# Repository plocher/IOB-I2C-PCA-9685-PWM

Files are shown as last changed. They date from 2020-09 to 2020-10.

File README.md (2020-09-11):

# IOB-I2C-PCA-9685-PWM
## License: CERN Open Hardware Licence v1.2

IOB I2C PCA9685 PWN driver

### Specifications

 * The PCA9685 is an i2c-controlled PWM driver with a built in free running clock.
 * The board is 5V compliant, which means you can control it from a 3.3V microcontroller and still safely drive up to 6V outputs (for LEDS and Servos)
 * 6 address select pins support up to 62 of these on a single I2C bus
 * Adjustable frequency PWM up to about 1.6 KHz
 * 12-bit resolution for each output
 * Configurable push-pull or open-drain output
 * Output enable pin to quickly disable all the outputs

### Communication Protocol

```C++
Simple I2C 16-bit Reads and Writes:

void I2Cexpander::init9685(uint8_t i2caddr, uint16_t dir) {
    if (i2caddr < base9685) {
        _i2c_address = i2caddr + base9685;
    } else {
        _i2c_address = i2caddr;
    }
    Wire.beginTransmission(_i2c_address);
	Wire.write(PCA9685_MODE1);
	Wire.write(PCA9685_MODE1_SLEEP);
    Wire.endTransmission();  
    delay(1);
    // Set precaler: float prescaleval = ((_oscillator_freq / (freq * 4096.0)) + 0.5) - 1;
    // max 255, min 3
    // internal _oscillator_freq is 25MHz
    Wire.beginTransmission(_i2c_address);
	Wire.write(PCA9685_PRESCALE);
	Wire.write(6);	// a value of 6 is about a 1000 Hz refresh rate  Servos need 60Hz: 101
    Wire.endTransmission();  
    delay(1);
    Wire.beginTransmission(_i2c_address);
	Wire.write(PCA9685_MODE1);
	Wire.write(PCA9685_MODE1_RESTART | PCA9685_MODE1_AUTOINC | PCA9685_MODE1_ALLCALL);
    Wire.endTransmission();  
    delay(1);
    Wire.beginTransmission(_i2c_address);
	Wire.write(PCA9685_MODE2);
	Wire.write(PCA9685_MODE2_TOTEM | PCA9685_MODE2_OEOFF);
    Wire.endTransmission();  
    delay(1);
}

// read uses the config value to distinguish which LED to read/write

uint32_t I2Cexpander::read9685() {
    uint32_t data = 0;
    uint16_t startdata = 0;
    uint16_t stopdata = 0;
    Wire.beginTransmission(_i2c_address);
    Wire.write(PCA9685_BASE_LED0 + (_config * 4));
    int n = Wire.endTransmission(false);  
    if (! ((n == 0) || (n ==7)) ) {
		return (_last);
    }
    Wire.requestFrom(_i2c_address, (uint8_t)4, (uint8_t)1);
    startdata = Wire.read();
    startdata |= (Wire.read() << 8);  
    stopdata = Wire.read();
    stopdata |= (Wire.read() << 8);  
	if (stopdata == startdata)     data = 0;
	else if (stopdata < startdata) data = startdata + stopdata & 0x0FFF;
	else                           data = stopdata - startdata;
    return data;
}

void I2Cexpander::write9685(uint32_t data) {
    /*
     * The chip has a freerunning counter (0..4095, 0x0000 to 0x0FFF)
     * LED#_ON_H/L  bits 0..11 are start 'time' for turn on
     *    Bit 12 (0x1000) means CONSTANT ON, unless OFF bit is also set
     * LED#_OFF_H/L bits 0..11 are start 'time' for turn off
     *    Bit 12 (0x1000) means CONSTANT OFF, overrides any ON setting
     */
    data = data & 0x0FFF;

    //  Stagger starting phase to ensure each string is independent, to reduce power supply spiking
    int start = (_config * 0x0F); // use LED num as beginning count...

    unsigned int end = (data + start) % 0x0FFF;		// 12 bits = 4096
    int b1 = (start     ) & 0x00FF; // low byte ...
    int b2 = (start >> 8) & 0x000F; // ... and high nibble
    int e1 = (end       ) & 0x00FF; // low byte ...
    int e2 = (end   >> 8) & 0x000F; // ... and high nibble

    if (data == 0x0FFF) {		// FULL ON
        b2 |= 0x1000;
    } else if (data == 0x0000) {	// FULL OFF
        e2 |= 0x1000;
    }

    Wire.beginTransmission(_i2c_address);
    Wire.write(PCA9685_BASE_LED0 + (_config * 4));

    Wire.write(b1);  
    Wire.write(b2);  
    Wire.write(e1);  
    Wire.write(e2);  

    Wire.endTransmission();  
}

```

See [I2Cexpander-lib](/pages/I2Cexpander "wikilink") for a more complete interface
library.

### Addressing
The addres selection for the PCA9685 allows for 62 devices, addresses 0x40 to 0x7F.
The board has dip switches for A0 through A5, A6 is hardcoded to "1" in the chip.

**A6**|**A5**|**A4**|**A3**|**A2**|**A1**|**A0**|**ADDRESS (HEX)**
:-----:|:-----:|:-----:|:-----:|:-----:|:-----:|:-----:|:-----:
1|0|0| 0|0|0|0 | 0x40
1|0|0| 0|0|0|1 | 0x41
1|0|0| 0|0|1|0 | 0x42
1|0|0| 0|0|1|1 | 0x43
1|0|0| 0|1|0|0 | 0x44
1|0|0| 0|1|0|1 | 0x45
1|0|0| 0|1|1|0 | 0x46
1|0|0| 0|1|1|1 | 0x47
1|0|0| 1|0|0|0 | 0x48
1|0|0| 1|0|0|1 | 0x49
1|0|0| 1|0|1|0 | 0x4A
1|0|0| 1|0|1|1 | 0x4B
1|0|0| 1|1|0|0 | 0x4C
1|0|0| 1|1|0|1 | 0x4D
1|0|0| 1|1|1|0 | 0x4E
1|0|0| 1|1|1|1 | 0x4F
1|0|1| 0|0|0|0 | 0x50
1|0|1| 0|0|0|1 | 0x51
1|0|1| 0|0|1|0 | 0x52
1|0|1| 0|0|1|1 | 0x53
1|0|1| 0|1|0|0 | 0x54
1|0|1| 0|1|0|1 | 0x55
1|0|1| 0|1|1|0 | 0x56
1|0|1| 0|1|1|1 | 0x57
1|0|1| 1|0|0|0 | 0x58
1|0|1| 1|0|0|1 | 0x59
1|0|1| 1|0|1|0 | 0x5A
1|0|1| 1|0|1|1 | 0x5B
1|0|1| 1|1|0|0 | 0x5C
1|0|1| 1|1|0|1 | 0x5D
1|0|1| 1|1|1|0 | 0x5E
1|0|1| 1|1|1|1 | 0x5F
1|1|0| 0|0|0|0 | 0x60
1|1|0| 0|0|0|1 | 0x61
1|1|0| 0|0|1|0 | 0x62
1|1|0| 0|0|1|1 | 0x63
1|1|0| 0|1|0|0 | 0x64
1|1|0| 0|1|0|1 | 0x65
1|1|0| 0|1|1|0 | 0x66
1|1|0| 0|1|1|1 | 0x67
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

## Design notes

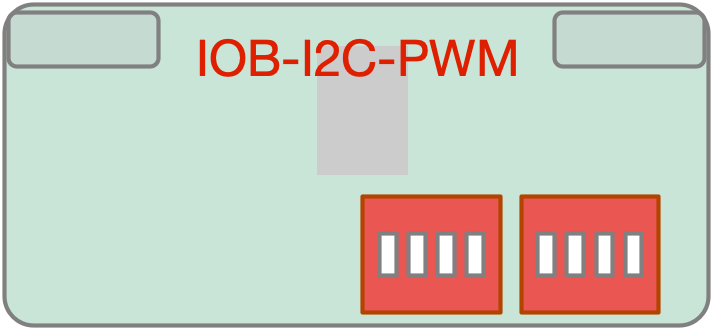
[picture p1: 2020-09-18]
IOB-I2C-PCA9685-PWM-Graphic.png

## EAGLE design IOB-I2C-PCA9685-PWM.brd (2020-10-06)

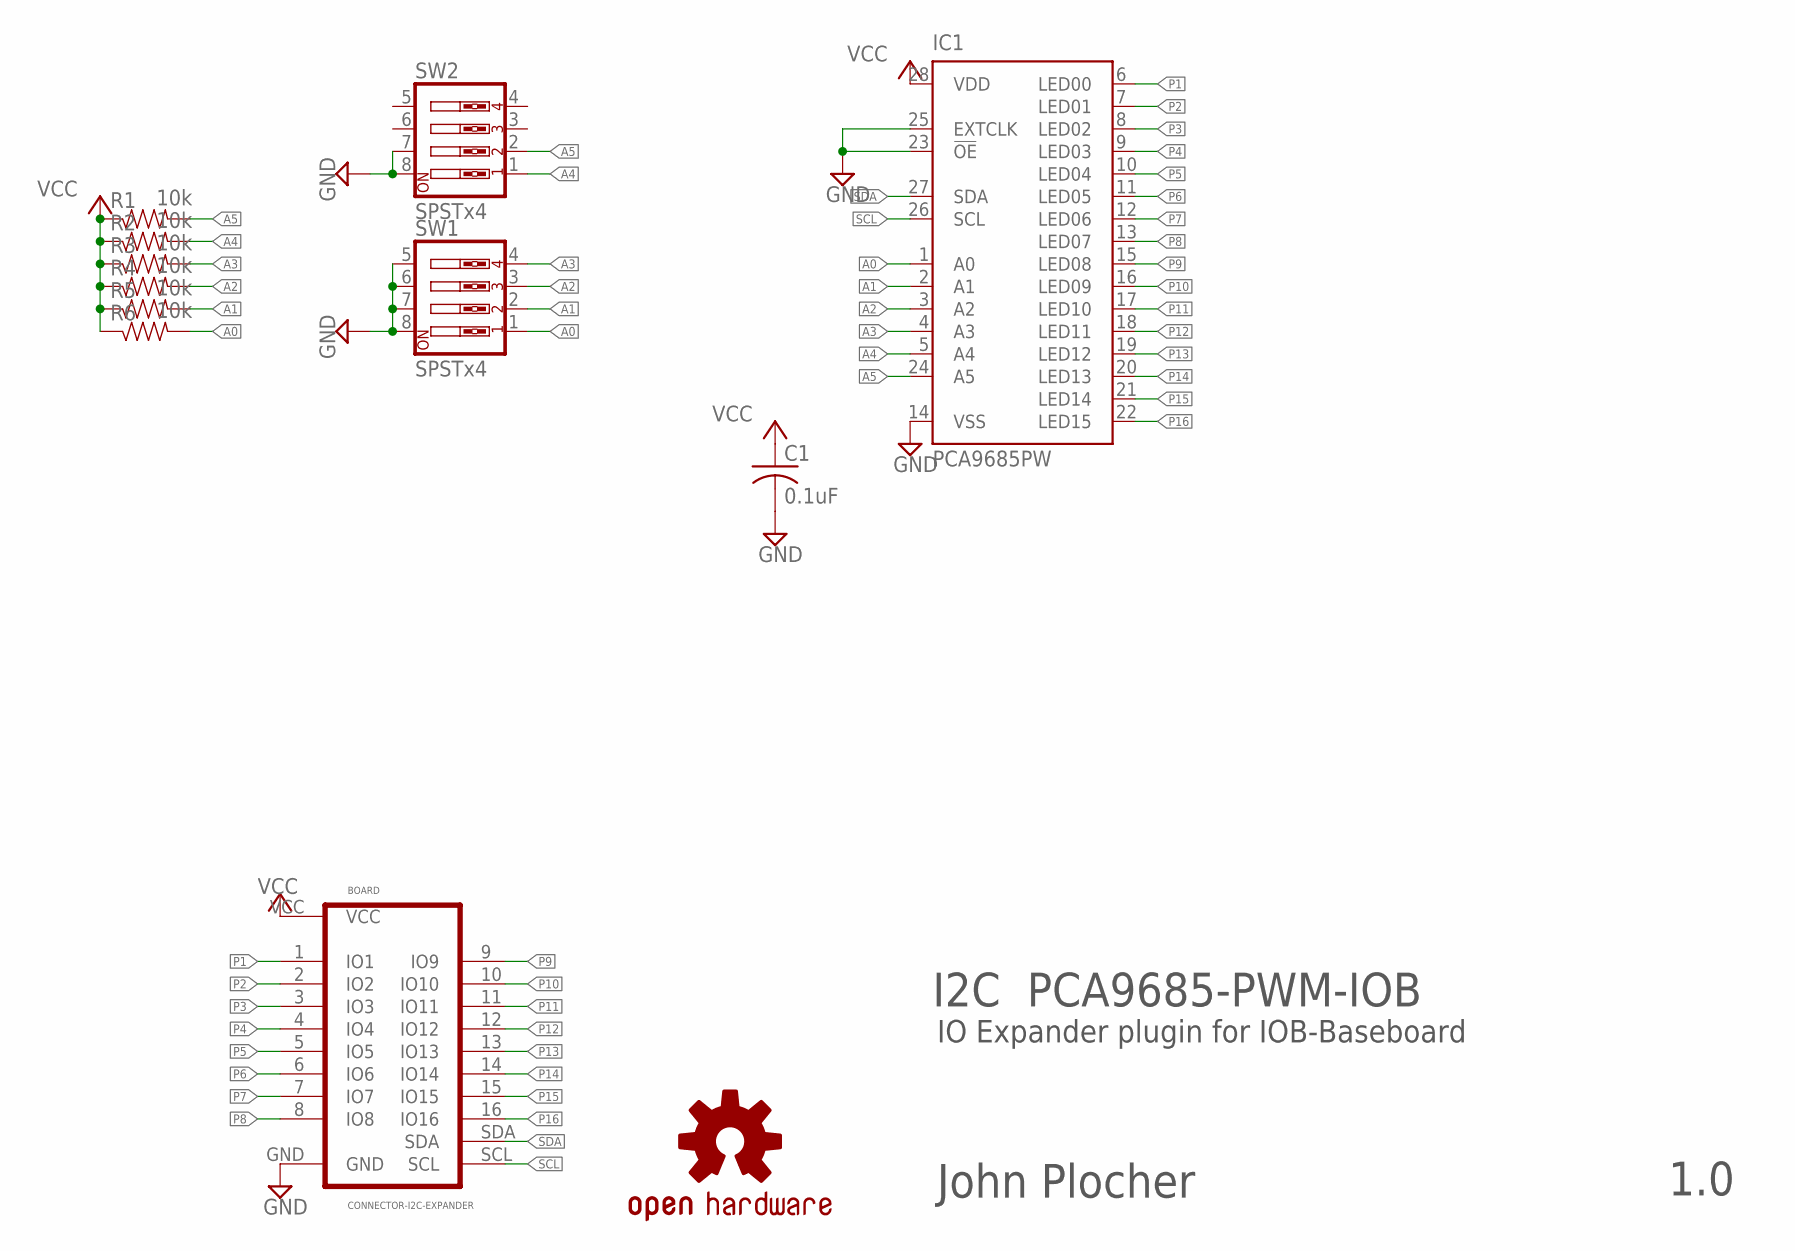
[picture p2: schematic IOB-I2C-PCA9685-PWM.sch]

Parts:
BOARD: CONNECTOR-I2C-EXPANDER; I2C-EXPANDER
C1: 0.1uF; 0603-CAP
IC1: PCA9685PW; TSSOP28
R1, R2, R3, R4, R5, R6: 10k; 0603-RES
SW1, SW2: SPSTx4; EDG-04
U$1: OSHW; OSHW-LOGO-L

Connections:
A0: IC1.1 (A0), R6.2, SW1.1
A1: IC1.2 (A1), R5.2, SW1.2
A2: IC1.3 (A2), R4.2, SW1.3
A3: IC1.4 (A3), R3.2, SW1.4
A4: IC1.5 (A4), R2.2, SW2.1
A5: IC1.24 (A5), R1.2, SW2.2
GND: BOARD.GND, C1.2, IC1.14 (VSS), IC1.23 (!OE), IC1.25 (EXTCLK), SW1.5, SW1.6, SW1.7, SW1.8, SW2.7, SW2.8
P1: BOARD.1 (IO1), IC1.6 (LED00)
P2: BOARD.2 (IO2), IC1.7 (LED01)
P3: BOARD.3 (IO3), IC1.8 (LED02)
P4: BOARD.4 (IO4), IC1.9 (LED03)
P5: BOARD.5 (IO5), IC1.10 (LED04)
P6: BOARD.6 (IO6), IC1.11 (LED05)
P7: BOARD.7 (IO7), IC1.12 (LED06)
P8: BOARD.8 (IO8), IC1.13 (LED07)
P9: BOARD.9 (IO9), IC1.15 (LED08)
P10: BOARD.10 (IO10), IC1.16 (LED09)
P11: BOARD.11 (IO11), IC1.17 (LED10)
P12: BOARD.12 (IO12), IC1.18 (LED11)
P13: BOARD.13 (IO13), IC1.19 (LED12)
P14: BOARD.14 (IO14), IC1.20 (LED13)
P15: BOARD.15 (IO15), IC1.21 (LED14)
P16: BOARD.16 (IO16), IC1.22 (LED15)
SCL: BOARD.SCL, IC1.26 (SCL)
SDA: BOARD.SDA, IC1.27 (SDA)
VCC: BOARD.VCC, C1.1, IC1.28 (VDD), R1.1, R2.1, R3.1, R4.1, R5.1, R6.1

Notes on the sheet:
I2C PCA9685-PWM-IOB
IO Expander plugin for IOB-Baseboard
John Plocher
1.0

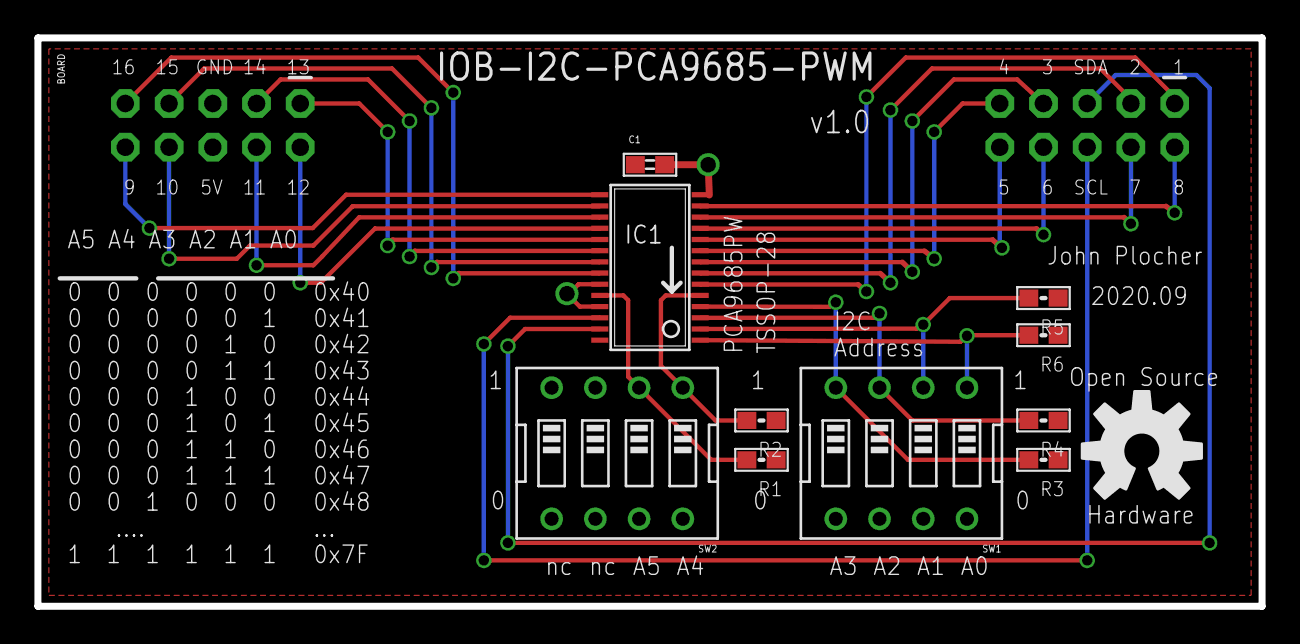
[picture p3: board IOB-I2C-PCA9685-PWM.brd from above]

Board: 2 copper layers, 71.1 x 33.0 mm, 12 parts (0 on the bottom side), 26 nets.

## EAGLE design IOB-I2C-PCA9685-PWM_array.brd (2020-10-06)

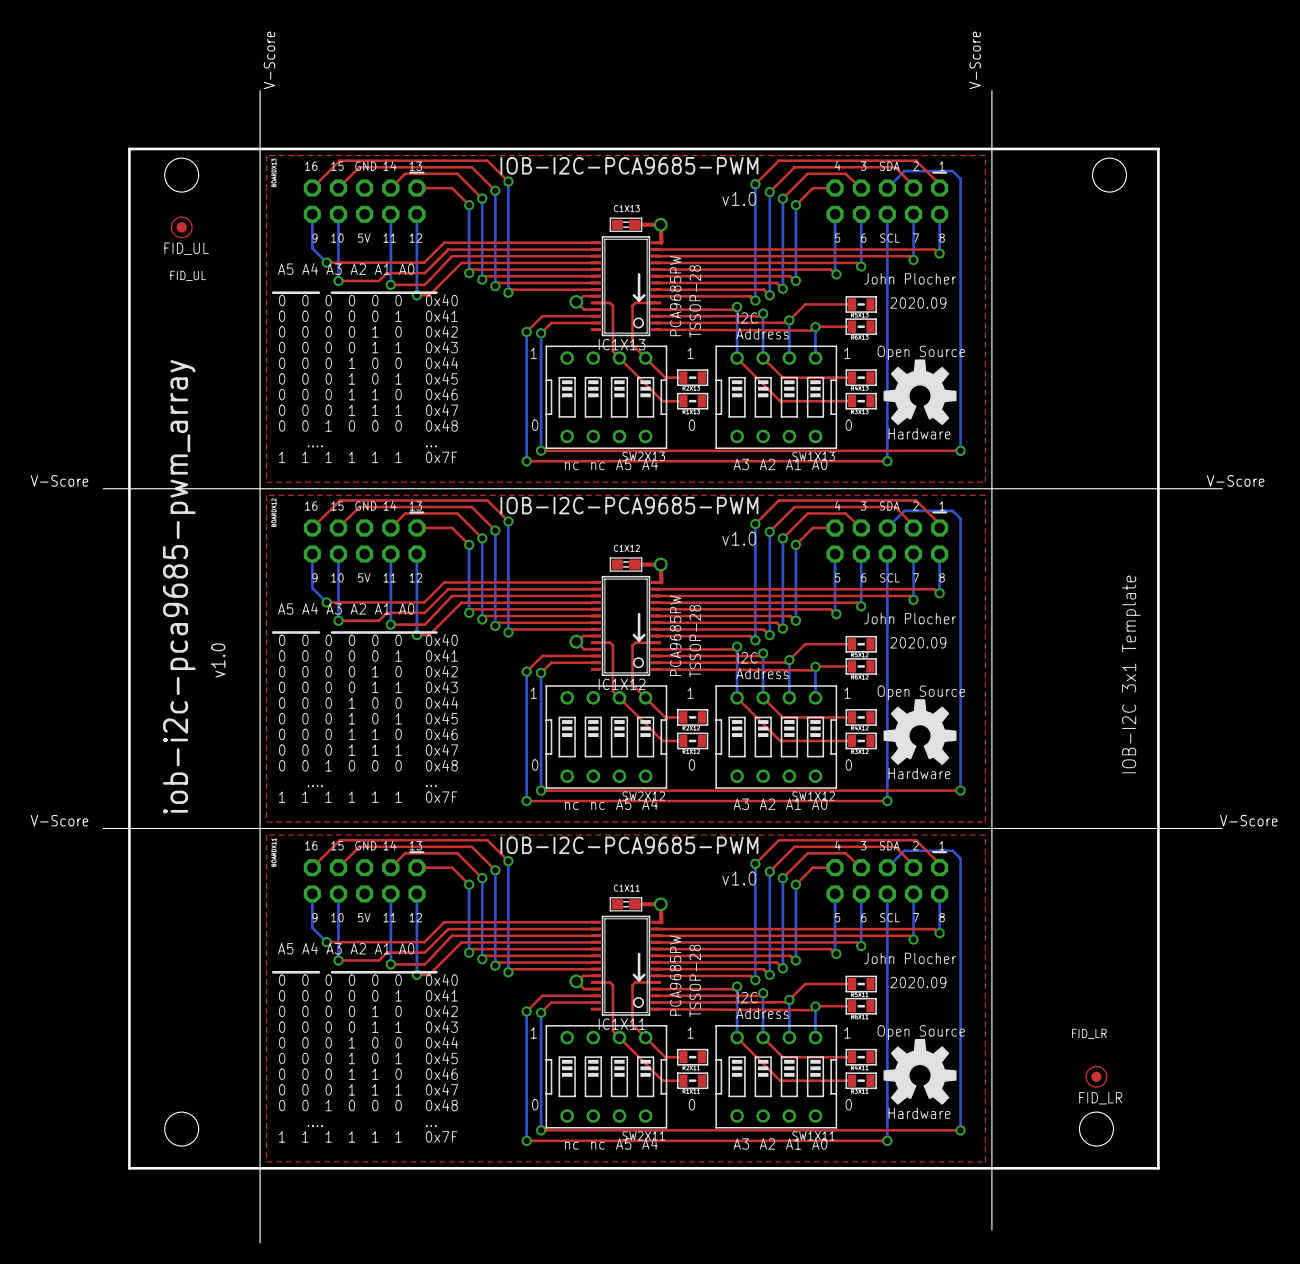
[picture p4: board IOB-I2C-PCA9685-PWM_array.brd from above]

Board: 2 copper layers, 108.7 x 112.0 mm, 39 parts (0 on the bottom side), 78 nets.

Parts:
BOARDX11, BOARDX12, BOARDX13: CONNECTOR-I2C-EXPANDER; I2C-EXPANDER
C1X11, C1X12, C1X13: 0.1uF; 0603-CAP
FID_LR: FIDUCIAL; FIDUCIAL_1MM
FID_UL: FIDUCIAL; FIDUCIAL_1MM
IC1X11, IC1X12, IC1X13: PCA9685PW; TSSOP28
R1X11, R1X12, R1X13, R2X11, R2X12, R2X13, R3X11, R3X12, R3X13, R4X11, R4X12, R4X13, R5X11, R5X12, R5X13, R6X11, R6X12, R6X13: 10k; 0805-RES
SW1X11, SW1X12, SW1X13, SW2X11, SW2X12, SW2X13: SPSTx4; EDG-04
U$1X11, U$1X12, U$1X13: OSHW; OSHW-LOGO-L
U$5X1: BOARD; BOARD-TEMPLATE-IOB-I2C-3X1-ARRAY

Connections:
A0X11: IC1X11.1, R6X11.2, SW1X11.1
A0X12: IC1X12.1, R6X12.2, SW1X12.1
A0X13: IC1X13.1, R6X13.2, SW1X13.1
A1X11: IC1X11.2, R5X11.2, SW1X11.2
A1X12: IC1X12.2, R5X12.2, SW1X12.2
A1X13: IC1X13.2, R5X13.2, SW1X13.2
A2X11: IC1X11.3, R4X11.2, SW1X11.3
A2X12: IC1X12.3, R4X12.2, SW1X12.3
A2X13: IC1X13.3, R4X13.2, SW1X13.3
A3X11: IC1X11.4, R3X11.2, SW1X11.4
A3X12: IC1X12.4, R3X12.2, SW1X12.4
A3X13: IC1X13.4, R3X13.2, SW1X13.4
A4X11: IC1X11.5, R2X11.2, SW2X11.1
A4X12: IC1X12.5, R2X12.2, SW2X12.1
A4X13: IC1X13.5, R2X13.2, SW2X13.1
A5X11: IC1X11.24, R1X11.2, SW2X11.2
A5X12: IC1X12.24, R1X12.2, SW2X12.2
A5X13: IC1X13.24, R1X13.2, SW2X13.2
GNDX11: BOARDX11.GND, C1X11.2, IC1X11.14, IC1X11.23, IC1X11.25, SW1X11.5, SW1X11.6, SW1X11.7, SW1X11.8, SW2X11.7, SW2X11.8
GNDX12: BOARDX12.GND, C1X12.2, IC1X12.14, IC1X12.23, IC1X12.25, SW1X12.5, SW1X12.6, SW1X12.7, SW1X12.8, SW2X12.7, SW2X12.8
GNDX13: BOARDX13.GND, C1X13.2, IC1X13.14, IC1X13.23, IC1X13.25, SW1X13.5, SW1X13.6, SW1X13.7, SW1X13.8, SW2X13.7, SW2X13.8
P1X11: BOARDX11.1, IC1X11.6
P1X12: BOARDX12.1, IC1X12.6
P1X13: BOARDX13.1, IC1X13.6
P2X11: BOARDX11.2, IC1X11.7
P2X12: BOARDX12.2, IC1X12.7
P2X13: BOARDX13.2, IC1X13.7
P3X11: BOARDX11.3, IC1X11.8
P3X12: BOARDX12.3, IC1X12.8
P3X13: BOARDX13.3, IC1X13.8
P4X11: BOARDX11.4, IC1X11.9
P4X12: BOARDX12.4, IC1X12.9
P4X13: BOARDX13.4, IC1X13.9
P5X11: BOARDX11.5, IC1X11.10
P5X12: BOARDX12.5, IC1X12.10
P5X13: BOARDX13.5, IC1X13.10
P6X11: BOARDX11.6, IC1X11.11
P6X12: BOARDX12.6, IC1X12.11
P6X13: BOARDX13.6, IC1X13.11
P7X11: BOARDX11.7, IC1X11.12
P7X12: BOARDX12.7, IC1X12.12
P7X13: BOARDX13.7, IC1X13.12
P8X11: BOARDX11.8, IC1X11.13
P8X12: BOARDX12.8, IC1X12.13
P8X13: BOARDX13.8, IC1X13.13
P9X11: BOARDX11.9, IC1X11.15
P9X12: BOARDX12.9, IC1X12.15
P9X13: BOARDX13.9, IC1X13.15
P10X11: BOARDX11.10, IC1X11.16
P10X12: BOARDX12.10, IC1X12.16
P10X13: BOARDX13.10, IC1X13.16
P11X11: BOARDX11.11, IC1X11.17
P11X12: BOARDX12.11, IC1X12.17
P11X13: BOARDX13.11, IC1X13.17
P12X11: BOARDX11.12, IC1X11.18
P12X12: BOARDX12.12, IC1X12.18
P12X13: BOARDX13.12, IC1X13.18
P13X11: BOARDX11.13, IC1X11.19
P13X12: BOARDX12.13, IC1X12.19
P13X13: BOARDX13.13, IC1X13.19
P14X11: BOARDX11.14, IC1X11.20
P14X12: BOARDX12.14, IC1X12.20
P14X13: BOARDX13.14, IC1X13.20
P15X11: BOARDX11.15, IC1X11.21
P15X12: BOARDX12.15, IC1X12.21
P15X13: BOARDX13.15, IC1X13.21
P16X11: BOARDX11.16, IC1X11.22
P16X12: BOARDX12.16, IC1X12.22
P16X13: BOARDX13.16, IC1X13.22
SCLX11: BOARDX11.SCL, IC1X11.26
SCLX12: BOARDX12.SCL, IC1X12.26
SCLX13: BOARDX13.SCL, IC1X13.26
SDAX11: BOARDX11.SDA, IC1X11.27
SDAX12: BOARDX12.SDA, IC1X12.27
SDAX13: BOARDX13.SDA, IC1X13.27
VCCX11: BOARDX11.VCC, C1X11.1, IC1X11.28, R1X11.1, R2X11.1, R3X11.1, R4X11.1, R5X11.1, R6X11.1
VCCX12: BOARDX12.VCC, C1X12.1, IC1X12.28, R1X12.1, R2X12.1, R3X12.1, R4X12.1, R5X12.1, R6X12.1
VCCX13: BOARDX13.VCC, C1X13.1, IC1X13.28, R1X13.1, R2X13.1, R3X13.1, R4X13.1, R5X13.1, R6X13.1

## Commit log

2020-09-11 Initial version
    [IOB-I2C-PCA-9685-PWM.brd, IOB-I2C-PCA-9685-PWM.sch, IOB-I2C-PCA-9685-PWM_array.brd]
2020-09-11 fixed naming style
    [IOB-I2C-PCA9685-PWM.brd, IOB-I2C-PCA9685-PWM.sch, IOB-I2C-PCA9685-PWM_array.brd]
2020-10-05 added values for connectors
    [IOB-I2C-PCA9685-PWM_array.brd]
2020-10-06 normalized values
    [IOB-I2C-PCA9685-PWM.brd, IOB-I2C-PCA9685-PWM.sch, IOB-I2C-PCA9685-PWM_array.brd]

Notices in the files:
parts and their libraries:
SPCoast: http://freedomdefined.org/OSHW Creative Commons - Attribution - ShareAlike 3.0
